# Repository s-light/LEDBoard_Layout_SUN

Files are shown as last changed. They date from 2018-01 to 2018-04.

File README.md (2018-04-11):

<!--lint disable list-item-indent-->

# LEDBoard Layout 'Sun'
'Sun' build with [LEDBoard 4x4 16bit](https://github.com/s-light/LEDBoard_4x4_16bit)

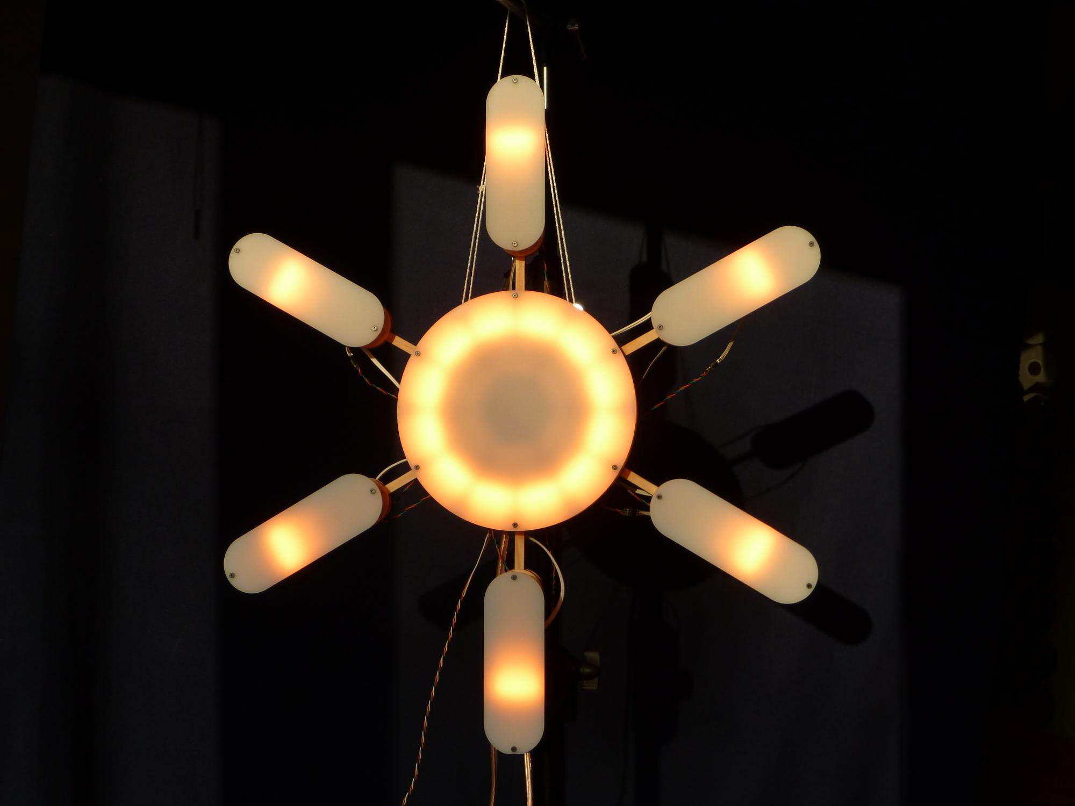
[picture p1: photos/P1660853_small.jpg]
Sun


[Video: LEDBoard Layout Sun - first test](https://vimeo.com/253356118)

## arduino test sketch
have a look at [sw/LEDBoard_HWTest_Sun](sw/LEDBoard_HWTest_Sun/readme.md)
how to setup an arduino board to do basic testings for the completed sun.

## control software
to control the sun / display content i have chosen to separate
this in two parts:

First i use an Arietta embedded linux board as
Network (Art-Net and E1.31 / sACN) two SPI/TLC5971 converter.
Additionally this should get basic 'playback' capabilities.
Something like  
`automatically start a rainbow loop on system-startup`  
--> for this task every embedded board should fit that has a free native SPI output
and can run debian based linux (for example Raspberry Pi) -
for ease of use i use the OLA software to create the Network-SPI bridge.
(currently there is a fork where i develop the [TLC5971 functionality](https://github.com/s-light/ola/tree/SPI_TLC5971_new))

Second there will be 'some Application' of some form running on an power-full
computer to generate the Data.
Ideas:
- [processing](https://processing.org/)
- [openFrameworks (OF)](http://openframeworks.cc/)
- [Pure Data (pd)](http://puredata.info/)

SW is a big TODO :-)

## mounting sun
in [mounting_sun/readme.md](mounting_sun/readme.md) are all information
regarding the Hardware / frame to build the sun.

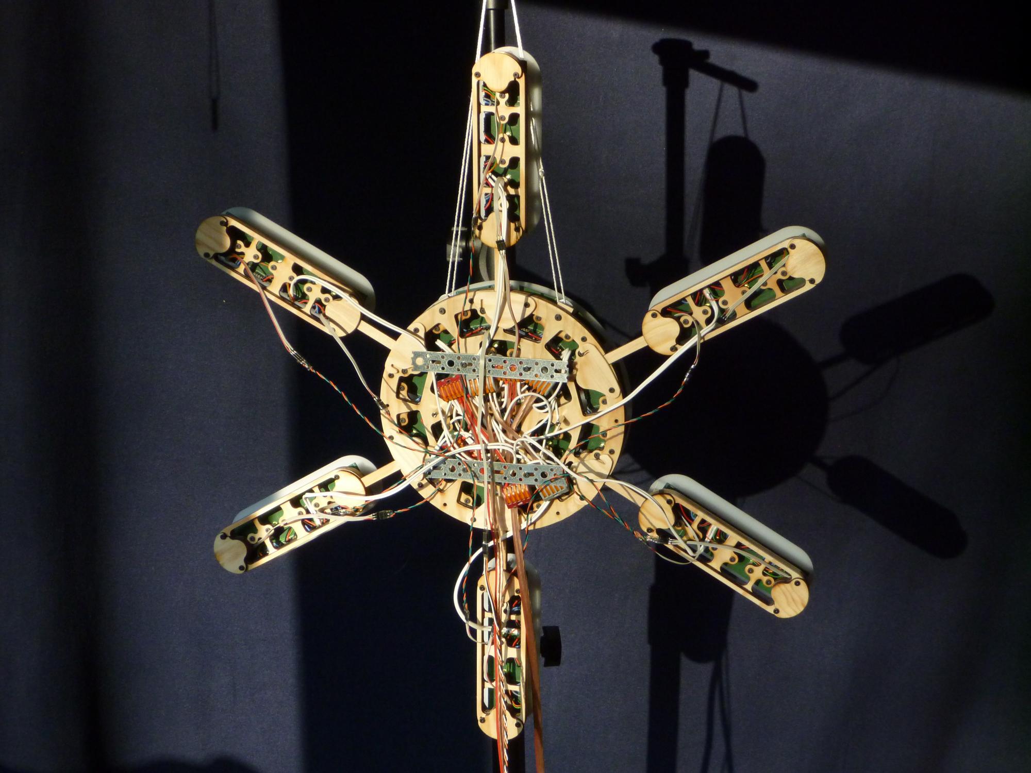
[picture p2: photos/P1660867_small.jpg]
Mounting Sun


---
# License
all* Software in this repository is license under MIT License (see [LICENSE file](LICENSE))

all* HW / Design files are licensed as CC-BY

\*besides if otherwise state at the files/subfolders themselves. 

<!-- License info -->
<a rel="license" href="http://creativecommons.org/licenses/by/4.0/">
    
</a><br />
<span xmlns:dct="http://purl.org/dc/terms/" property="dct:title">
    LEDBoard_Layout_Sun
</span>
by
<a xmlns:cc="http://creativecommons.org/ns#" href="https://github.com/s-light/LEDBoard_Layout_Sun" property="cc:attributionName" rel="cc:attributionURL">
    Stefan Krüger (s-light)
</a>
is licensed under a
<a rel="license" href="http://creativecommons.org/licenses/by/4.0/">
    Creative Commons Attribution 4.0 International License
</a>.

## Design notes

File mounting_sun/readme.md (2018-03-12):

<!--lint disable list-item-indent-->

# Mounting Sun

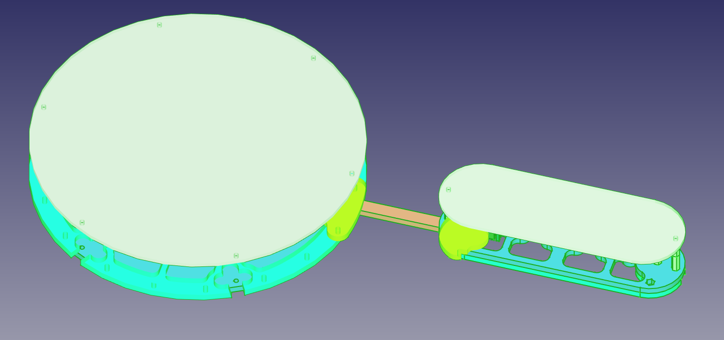
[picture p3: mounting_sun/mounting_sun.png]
Mounting Sun


full design: [mounting_sun.step](mounting_sun.step)

this is now version 2 - a redesign - this time made in FreeCAD v0.17 (daily) completely in 3d.

## parts-list

### laser-cutting
- Pine-Plywood (>=4mm thickness)
  - 6x [arm/arm_base.svg](arm/arm_base.svg)
  - 2x6x [arm/arm_socket.svg](arm/arm_socket.svg)
  - 12x [arm/arm_lock.svg](arm/arm_lock.svg)
  - 2x6x [connector/socket_connector_40mm.svg](connector/socket_connector_40mm.svg)
  - 6x [center/center_lock.svg](center/center_lock.svg)
  - 1x [center/center_base.svg](center/center_base.svg)
  - 1x [center/center_socket.svg](center/center_socket.svg)
  - 1x [center/center_socket2.svg](center/center_socket2.svg)
- [Plexiglas WH02 (3mm)](https://www.plexiglas-shop.com/DE/de/einseitig-satiniert-d3k0ydk22v3/plexiglas-satinice-weiss-wh02-sc-1jmuadz2jyj~p.html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)
  - 6x [arm/arm_diffusor.svg](arm/arm_diffusor.svg)
  - 1x [center/center_diffusor.svg](center/center_diffusor.svg)

### screws for LEDBoard mounting:
TODO: recalculate screws...
- 38*2*2 (=152)x [cylinder head - screw M3x10mm](https://www.wegertseder.com/ArticleDetails.aspx?ANR=2588-412)
- 38*2 (=76) [spacer M3x15mm](https://www.reichelt.de/index.html?ARTICLE=7120&GROUPID=7758&artnr=DI+15MM)

### screws for wood connections:
- 6*3 (=18)x [countersunk - screw M3x20mm](https://www.wegertseder.com/ArticleDetails.aspx?ANR=2606-242)
- 6*3 (=18)x [bolt M3](https://www.wegertseder.com/ArticleDetails.aspx?AKNUM=3991)

### cable

TODO:
for LEDBoard interconnections see Interconnection cables
cable type: 0,8mm solid copper conductor --> has to tightly fit in the LEDBoard sockets

#### power
- 2* 2m for main supply [4mm² Loudspeaker wire](https://www.reichelt.de/index.html?ARTICLE=9887&GROUPID=5034&artnr=LAT+400-5)
- 6* 350mm for arm supply [0.5mm² Loudspeaker wire](https://www.reichelt.de/index.html?ARTICLE=74777&GROUPID=5034&artnr=LAW+205-10)

### Power Supply
TODO

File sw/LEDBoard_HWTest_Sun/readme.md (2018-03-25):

<!--lint disable list-item-indent-->

# LEDBoard_HWTest_Sun

You need an Arduino compatible micro controller with a good amount of RAM.
i successfully tested an ATmega1284.
(32U4 is to small.)

This sketch has some Test-Patterns that use the full board-count of the sun.
One problem is the update rate.
as an simple  for loop to set all channels individually takes 36ms -
there is an additional 1ms to write data out to the tlc chips.

the sketch receives 5 channels of DMX from an external controller.
this setup is done so you can control this with with the
[LSM303_to_DMX](https://github.com/s-light/LSM303_to_DMX) Sketch.

the DMX receiving has some glitches and sometimes generates wrong values.
this only happens when the rendering/update process is active: `sequencer_running == true`
so seems there is some timing or interference problems in the thing...

the external control is active in only some of the sequence modes.
mainly in `sequencer_SPIRAL`:
- heading of the LSM303 controls the color (Hue),
- Y-Axis controls `sequencer_interval` mapped as 100-2000ms

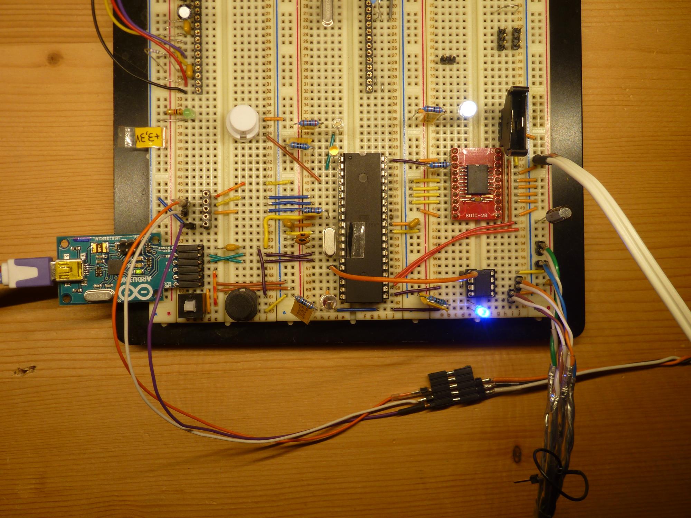
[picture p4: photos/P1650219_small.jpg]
test setup


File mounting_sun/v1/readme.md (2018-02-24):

<!--lint disable list-item-indent-->

# Mounting Sun

Mounting Sun

full design: [mounting_sun.step ](mounting_sun.svg)

this is now version 2 - a redesign - this time made in FreeCAD v0.17 (daily) completely in 3d.

## parts-list

### laser-cutting
- Wood (5mm thickness)
  - 6x [mounting_sun_arm_wood.svg](mounting_sun_arm_wood.svg)
  - 1x [mounting_sun_center_wood.svg](mounting_sun_center_wood.svg)
  - 6x [mounting_sun_connectors_wood.svg](mounting_sun_connectors_wood.svg)
- [Plexiglas WH02 (3mm)](https://www.plexiglas-shop.com/DE/de/einseitig-satiniert-d3k0ydk22v3/plexiglas-satinice-weiss-wh02-sc-1jmuadz2jyj~p.html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)
  - 6x [mounting_sun_arm_acryl.svg](mounting_sun_arm_acryl.svg)
  - 1x [mounting_sun_center_acryl.svg](mounting_sun_center_acryl.svg)

### screws for LEDBoard mounting:
- 38*2*2 (=152)x [cylinder head - screw M3x10mm](https://www.wegertseder.com/ArticleDetails.aspx?ANR=2588-412)
- 38*2 (=76) [spacer M3x15mm](https://www.reichelt.de/index.html?ARTICLE=7120&GROUPID=7758&artnr=DI+15MM)

### screws for wood connections:
- 6*3 (=18)x [countersunk - screw M3x20mm](https://www.wegertseder.com/ArticleDetails.aspx?ANR=2606-242)
- 6*3 (=18)x [bolt M3](https://www.wegertseder.com/ArticleDetails.aspx?AKNUM=3991)

### cable

TODO:
for LEDBoard interconnections see Interconnection cables
cable type: 0,8mm solid copper conductor --> has to tightly fit in the LEDBoard sockets

#### power
- 2* 2m for main supply [4mm² Loudspeaker wire](https://www.reichelt.de/index.html?ARTICLE=9887&GROUPID=5034&artnr=LAT+400-5)
- 6* 350mm for arm supply [0.5mm² Loudspeaker wire](https://www.reichelt.de/index.html?ARTICLE=74777&GROUPID=5034&artnr=LAW+205-10)

### Power Supply
TODO

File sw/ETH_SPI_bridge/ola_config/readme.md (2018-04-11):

<!--lint disable list-item-indent-->
# Mapping information:

the [ola_config](/ola_config) folder contains a set of olad configuration files.

these map the following Parts of the sun to universes:
## Center Part
- Starting on the top
- counting clockwise
- from outside to the inside

| Section | LEDBoards  | Universe |
| :--- | :--- | ---: |
| outer_ring_p1 | 1..4 | 1 |
| outer_ring_p2 | 5..8 | 2 |
| outer_ring_p3 | 9..12 | 3 |
| inner_ring_p1 | 13, 14, 15 | 4 |
| inner_ring_p2 | 16, 17, 18 | 5 |
| center_board  | 19 | 6 |

## Arms
- Starting on the top
- counting clockwise
- per arm - from inside to the outside

| Section | LEDBoards | Universe |
| :--- | :--- | ---: |
| arm_1 | 20..23 | 7 |
| arm_2 | 24..27 | 8 |
| arm_3 | 28..31 | 9 |
| arm_4 | 32..35 | 10 |
| arm_5 | 36..39 | 11 |
| arm_6 | 40..43 | 12 |

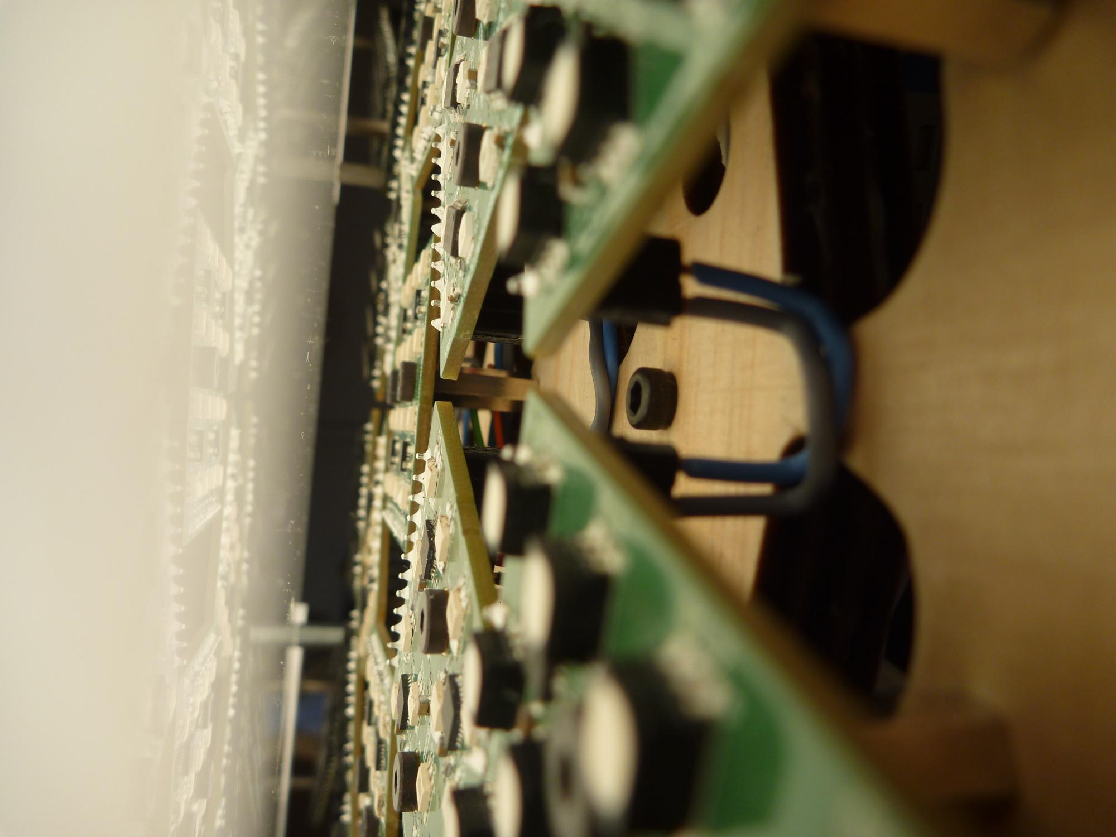
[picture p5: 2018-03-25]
photos/P1660885_small.jpg

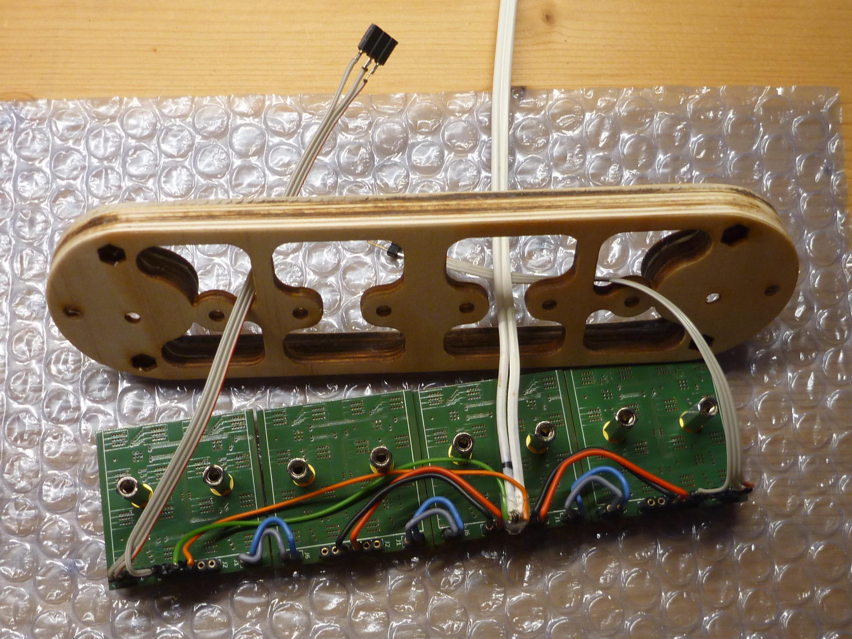
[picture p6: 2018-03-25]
photos/P1660823_crop.jpg

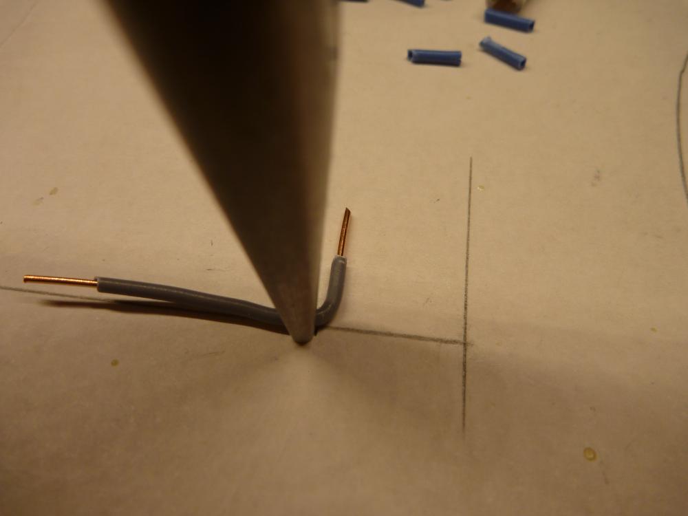
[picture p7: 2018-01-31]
photos/P1640711_small.jpg

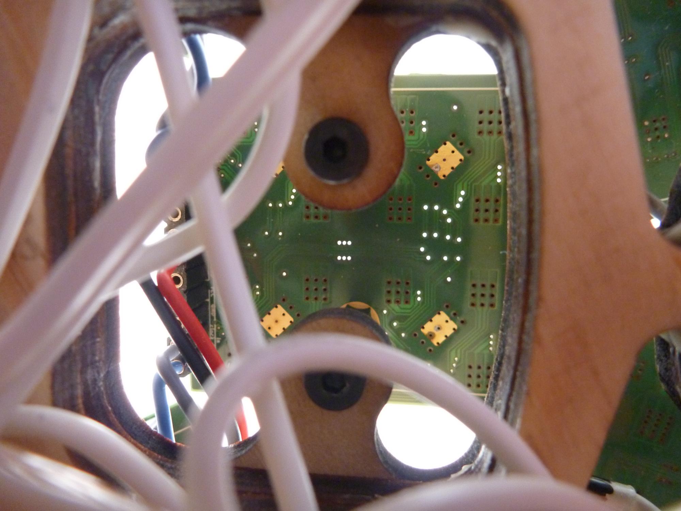
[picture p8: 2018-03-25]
photos/P1660899_small.jpg

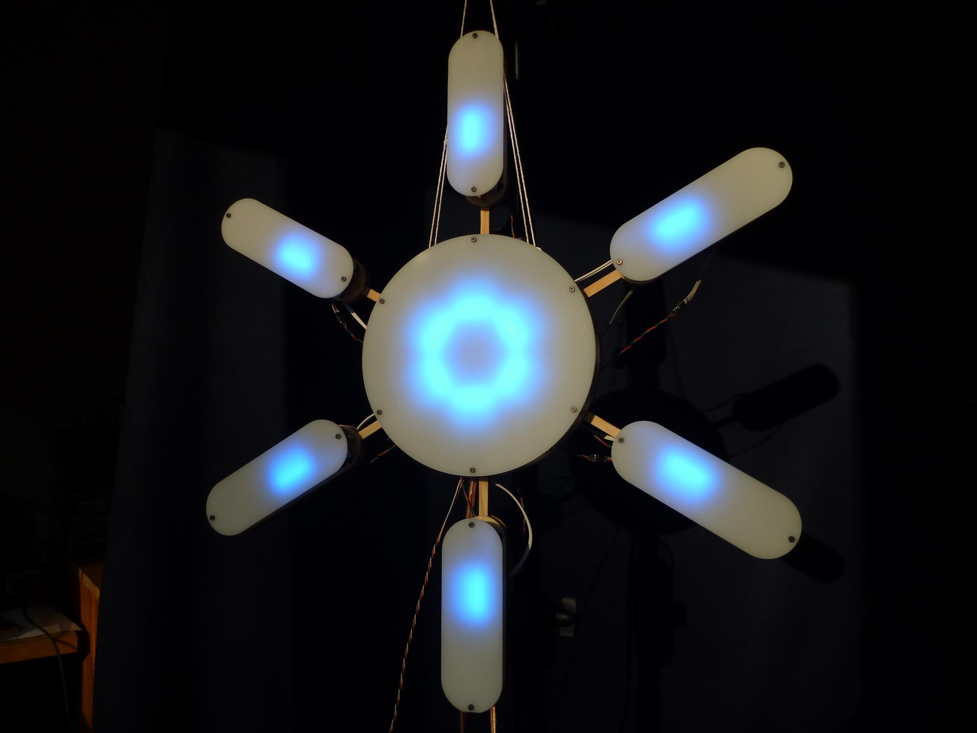
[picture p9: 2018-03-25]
photos/P1660846_small.jpg

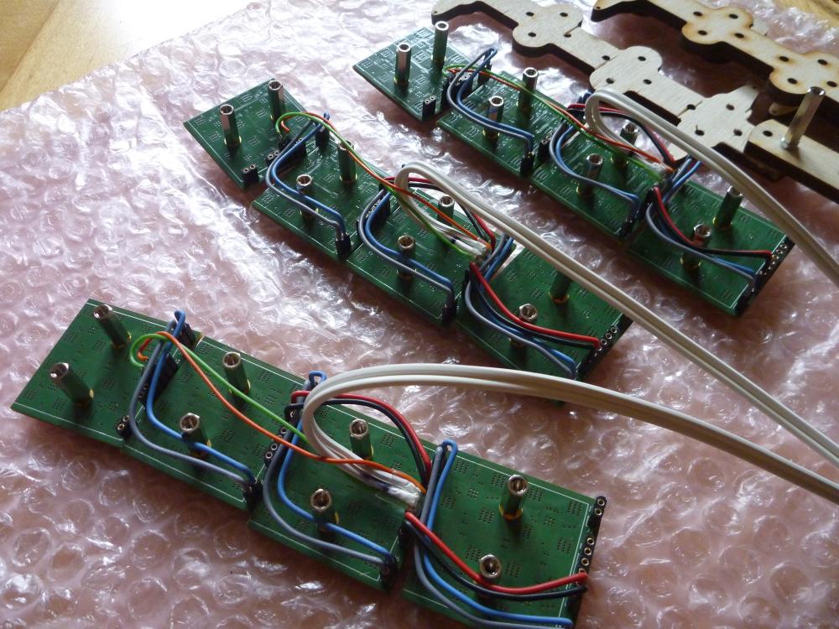
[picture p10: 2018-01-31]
photos/P1650089_small.jpg

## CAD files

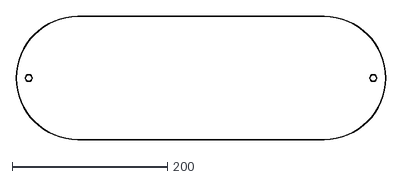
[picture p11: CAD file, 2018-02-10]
mounting_sun/arm/arm_diffusor.dxf
476.2 x 158.8

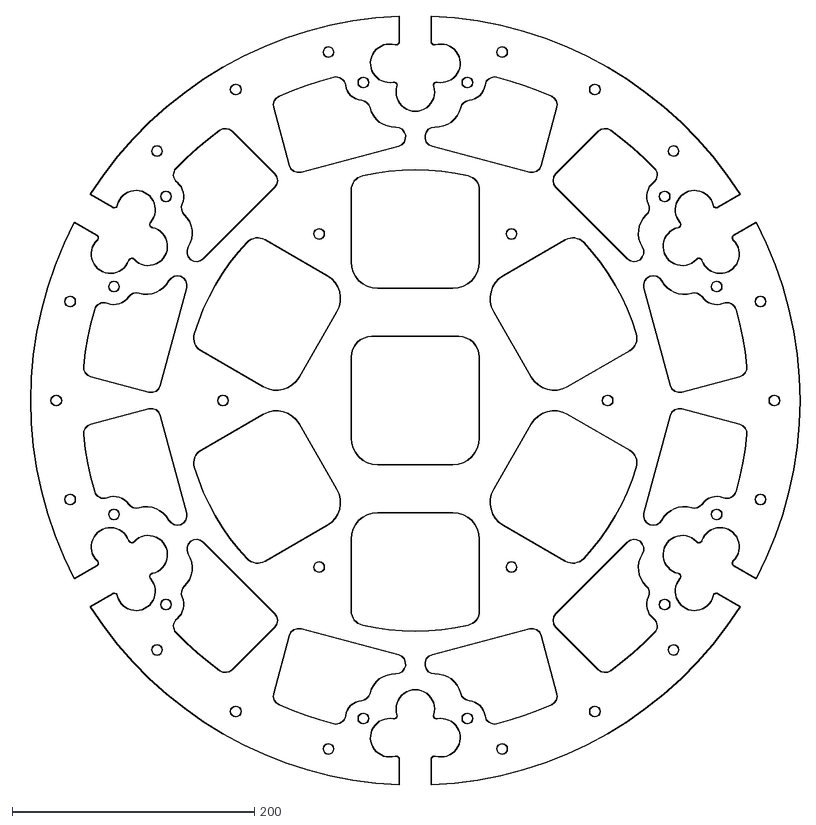
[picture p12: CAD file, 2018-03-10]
mounting_sun/center/center_socket2.dxf
647.1 x 634.4

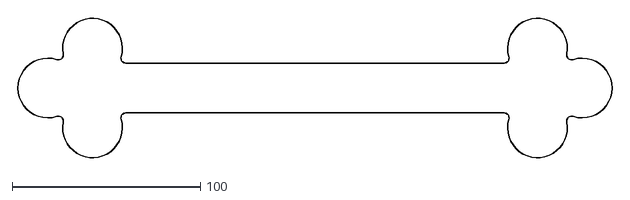
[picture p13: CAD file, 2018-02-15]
mounting_sun/connector/socket_connector_60mm.dxf
318.0 x 76.3

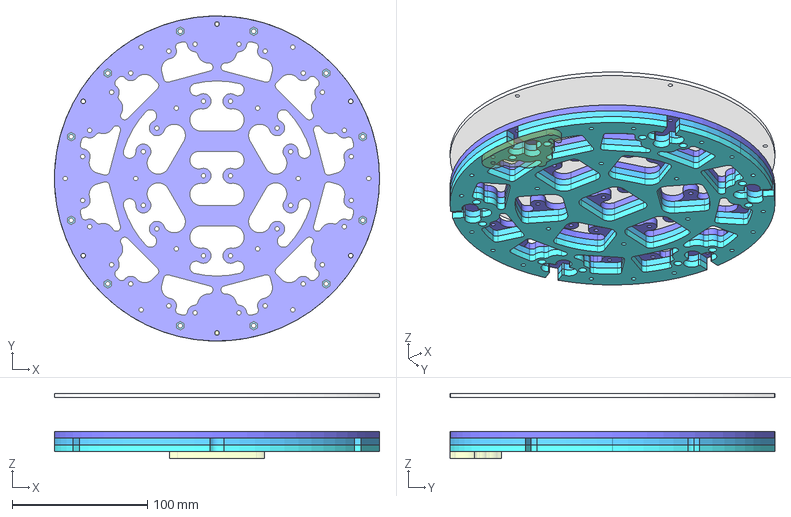
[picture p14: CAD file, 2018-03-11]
mounting_sun/mounting_sun.fcstd
240.0 x 239.9 x 48.0 mm
center_base_Body
center_socket_Body
center_diffusor_Body
center_lock_Body
center_socket2_Body

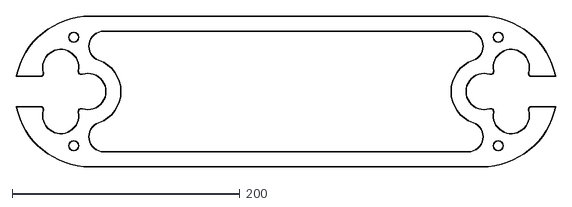
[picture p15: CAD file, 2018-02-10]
mounting_sun/arm/arm_socket.dxf
473.6 x 132.3

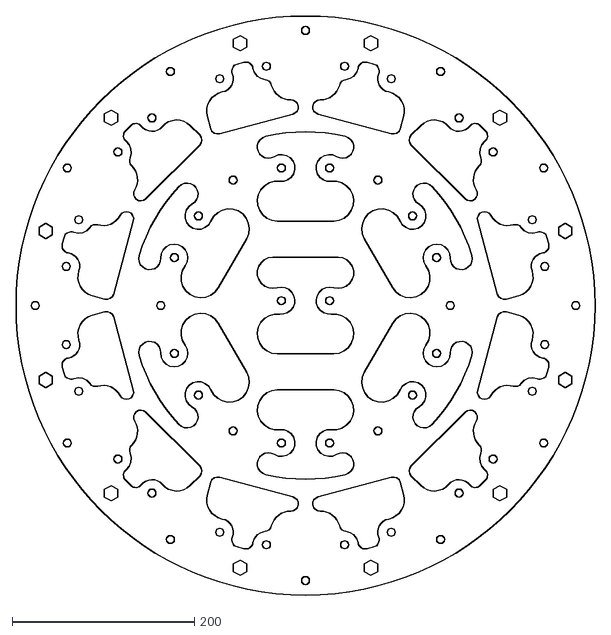
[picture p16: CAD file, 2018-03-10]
mounting_sun/center/center_base.dxf
635.0 x 635.0

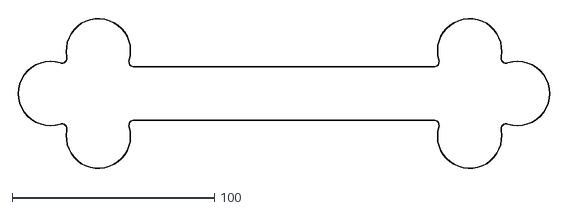
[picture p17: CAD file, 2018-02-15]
mounting_sun/connector/socket_connector_40mm.dxf
265.0 x 76.3

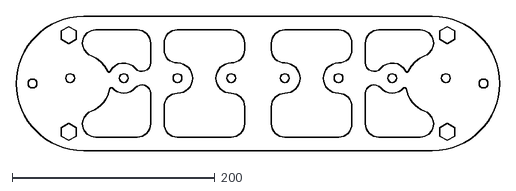
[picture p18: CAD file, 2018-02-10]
mounting_sun/arm/arm_base.dxf
476.2 x 132.3

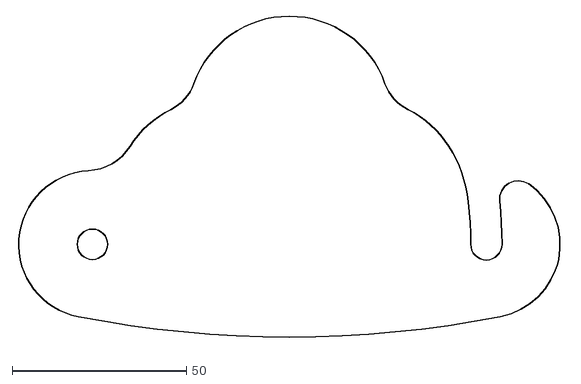
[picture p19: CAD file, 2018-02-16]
mounting_sun/center/center_lock.dxf
157.4 x 94.1

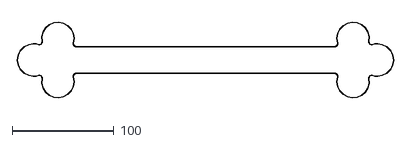
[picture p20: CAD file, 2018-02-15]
mounting_sun/connector/socket_connector_80mm.dxf
370.9 x 76.3

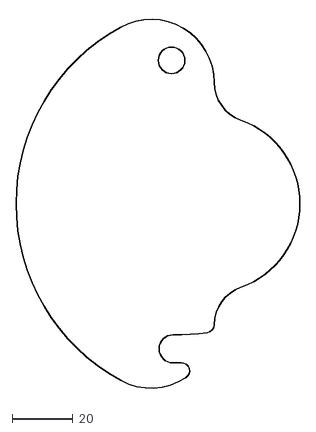
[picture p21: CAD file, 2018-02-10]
mounting_sun/arm/arm_lock.dxf
93.2 x 123.2

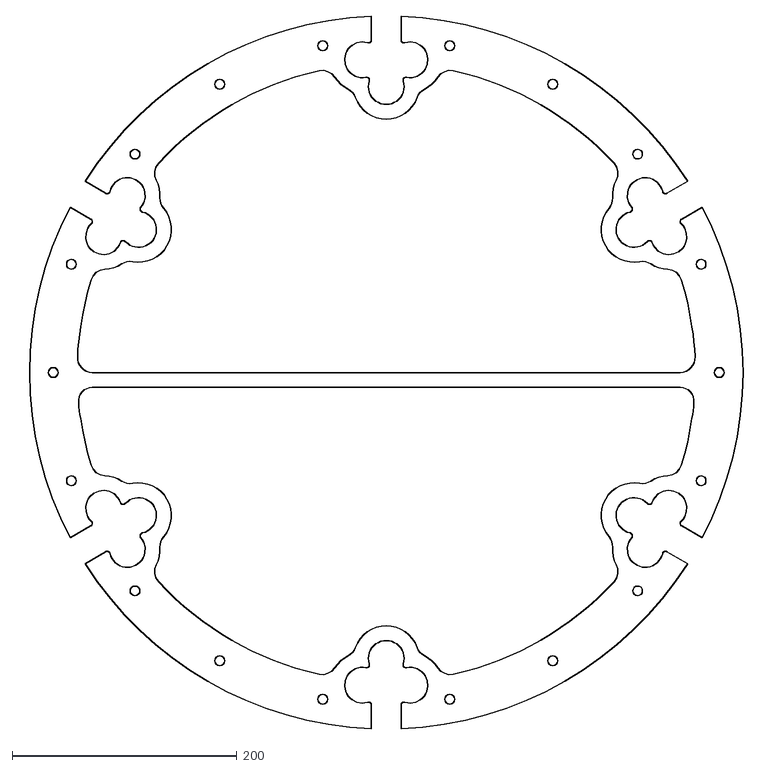
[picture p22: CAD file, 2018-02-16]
mounting_sun/center/center_socket.dxf
647.1 x 634.4

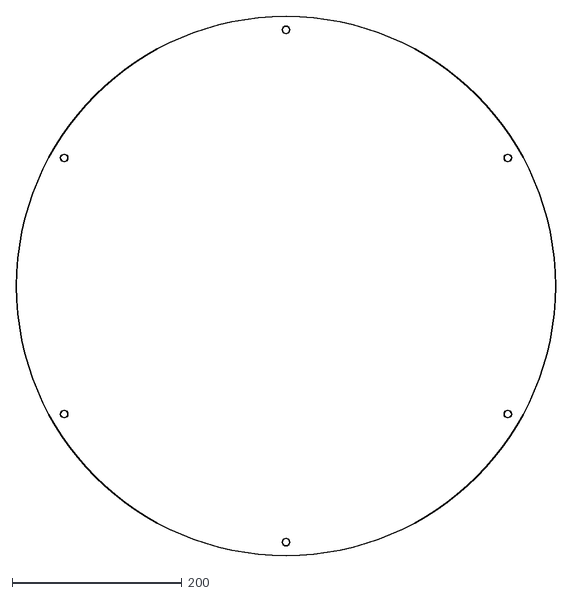
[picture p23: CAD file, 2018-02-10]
mounting_sun/center/center_diffusor.dxf
635.0 x 635.0

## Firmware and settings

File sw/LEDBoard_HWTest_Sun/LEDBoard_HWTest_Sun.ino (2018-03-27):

/******************************************************************************

    LEDBoard_HWTest_Sun
        test software for LEDBoard_4x4_16bit in mounting_sun
        debugout on usbserial interface: 115200baud

    hardware:
        Board:
            Arduino compatible (with serial port)
            with big RAM
            best fit: ATmega1284
            LED on pin 13
        Connections:
            D4 --> push button to GND
            SCK --> Clock input of TLC5791
            MOSI --> Data input of TLC5791
            only if TLC5791 is used with 5V@ VCC and VREG
            see www.ti.com/lit/ds/symlink/tlc5971.pdf
            page31 9.3 System Examples - Figure 38
            (eventually use a 74HC4050 as Levelshifter 5V-->3.8V
            if you use different VCC/VREG for Chips.)


    libraries used:
        ~ slight_DebugMenu
        ~ slight_Button
        ~ slight_FaderLin
            License: MIT
            written by stefan krueger (s-light),
                github@s-light.eu, http://s-light.eu, https://github.com/s-light/
        ~ Tlc59711.h
            License: MIT
            Copyright (c) 2016 Ulrich Stern
            https://github.com/ulrichstern/Tlc59711
        ~ DMXSerial
            Copyright (c) 2005-2012 by Matthias Hertel,
            http://www.mathertel.de
            license:
                See http://www.mathertel.de/License.aspx
                Software License Agreement (BSD License)

    written by stefan krueger (s-light),
        github@s-light.eu, http://s-light.eu, https://github.com/s-light/

    changelog / history
        check git commit messages

******************************************************************************/
/******************************************************************************
    The MIT License (MIT)

    Copyright (c) 2018 Stefan Krüger

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
    THE SOFTWARE IS PROVIDED "AS IS", WITHOUT WARRANTY OF ANY KIND, EXPRESS OR
    IMPLIED, INCLUDING BUT NOT LIMITED TO THE WARRANTIES OF MERCHANTABILITY,
    FITNESS FOR A PARTICULAR PURPOSE AND NONINFRINGEMENT. IN NO EVENT SHALL THE
    AUTHORS OR COPYRIGHT HOLDERS BE LIABLE FOR ANY CLAIM, DAMAGES OR OTHER
    LIABILITY, WHETHER IN AN ACTION OF CONTRACT, TORT OR OTHERWISE, ARISING FROM,
    OUT OF OR IN CONNECTION WITH THE SOFTWARE OR THE USE OR OTHER DEALINGS IN THE
    SOFTWARE.
******************************************************************************/

//~~~~~~~~~~~~~~~~~~~~~~~~~~~~~~~~~~~~~~~~~~~~~~~~~~~~~~~~~~~~~~~~~~~~
// Includes
//~~~~~~~~~~~~~~~~~~~~~~~~~~~~~~~~~~~~~~~~~~~~~~~~~~~~~~~~~~~~~~~~~~~~
// use "file.h" for files in same directory as .ino
// #include "file.h"
// use <file.h> for files in library directory
// #include <file.h>

#include <slight_DebugMenu.h>
#include <slight_FaderLin.h>
#include <slight_ButtonInput.h>

#include "LEDBoard.h"
#include "effect_engine.h"
#include "dmx_handling.h"

// create alias for namespace
namespace effe = effect_engine;

//~~~~~~~~~~~~~~~~~~~~~~~~~~~~~~~~~~~~~~~~~~~~~~~~~~~~~~~~~~~~~~~~~~~~
// Info
//~~~~~~~~~~~~~~~~~~~~~~~~~~~~~~~~~~~~~~~~~~~~~~~~~~~~~~~~~~~~~~~~~~~~
void sketchinfo_print(Print &out) {
    out.println();
    //             "|~~~~~~~~~|~~~~~~~~~|~~~..~~~|~~~~~~~~~|~~~~~~~~~|"
    out.println(F("~~~~~~~~~~~~~~~~~~~~~~~~~~~~~~~~~~~~~~~~~~~~~~~~~~"));
    out.println(F("|                       ^ ^                      |"));
    out.println(F("|                      (0,0)                     |"));
    out.println(F("|                      ( _ )                     |"));
    out.println(F("|                       \" \"                      |"));
    out.println(F("~~~~~~~~~~~~~~~~~~~~~~~~~~~~~~~~~~~~~~~~~~~~~~~~~~"));
    out.println(F("| LEDBoard_HWTest_Sun.ino"));
    out.println(F("|   Test LEDBoard_Layout_Sun"));
    out.println(F("|"));
    out.println(F("| This Sketch has a debug-menu:"));
    out.println(F("| send '?'+Return for help"));
    out.println(F("|"));
    out.println(F("| dream on & have fun :-)"));
    out.println(F("|"));
    out.println(F("~~~~~~~~~~~~~~~~~~~~~~~~~~~~~~~~~~~~~~~~~~~~~~~~~~"));
    out.println(F("|"));
    //out.println(F("| Version: Nov 11 2013  20:35:04"));
    out.print(F("| version: "));
    out.print(F(__DATE__));
    out.print(F("  "));
    out.print(F(__TIME__));
    out.println();
    out.println(F("|"));
    out.println(F("~~~~~~~~~~~~~~~~~~~~~~~~~~~~~~~~~~~~~~~~~~~~~~~~~~"));
    out.println();

    //out.println(__DATE__); Nov 11 2013
    //out.println(__TIME__); 20:35:04
}


// Serial.print to Flash: Notepad++ Replace RegEx
//     Find what:        Serial.print(.*)\("(.*)"\);
//     Replace with:    Serial.print\1\(F\("\2"\)\);



//~~~~~~~~~~~~~~~~~~~~~~~~~~~~~~~~~~~~~~~~~~~~~~~~~~~~~~~~~~~~~~~~~~~~
// definitions (global)
//~~~~~~~~~~~~~~~~~~~~~~~~~~~~~~~~~~~~~~~~~~~~~~~~~~~~~~~~~~~~~~~~~~~~


//~~~~~~~~~~~~~~~~~~~~~~~~~~~~~~~~~~~~~~~~~~
// Debug Output

Print &DebugOut = Serial;
Stream &DebugIn = Serial;
// attention: in setup_DebugOut 'Serial' is hardcoded used for initialisation


boolean infoled_state = 0;
const byte infoled_pin = 1;

unsigned long debugOut_LiveSign_TimeStamp_LastAction = 0;
const uint16_t debugOut_LiveSign_UpdateInterval = 1000; //ms

boolean debugOut_LiveSign_Serial_Enabled = 0;
boolean debugOut_LiveSign_LED_Enabled = 1;

unsigned long debugOut_dmx_TimeStamp_LastAction = 0;
const uint16_t debugOut_dmx_UpdateInterval = 500; //ms

boolean debugOut_dmx_Enabled = 0;

//~~~~~~~~~~~~~~~~~~~~~~~~~~~~~~~~~~~~~~~~~~
// Menu

// slight_DebugMenu(Stream &in_ref, Print &out_ref, uint8_t input_length_new);
slight_DebugMenu myDebugMenu(Serial, Serial, 15);

//~~~~~~~~~~~~~~~~~~~~~~~~~~~~~~~~~~~~~~~~~~
// button

const uint8_t button_pin = 3;

slight_ButtonInput button(
    0,  // byte cbID_New
    button_pin,  // byte cbPin_New,
    button_getInput,  // tCbfuncGetInput cbfuncGetInput_New,
    button_onEvent,  // tcbfOnEvent cbfCallbackOnEvent_New,
      30,  // const uint16_t cwDuration_Debounce_New = 30,
     500,  // const uint16_t cwDuration_HoldingDown_New = 1000,
      50,  // const uint16_t cwDuration_ClickSingle_New =   50,
     500,  // const uint16_t cwDuration_ClickLong_New =   3000,
     500   // const uint16_t cwDuration_ClickDouble_New = 1000
);

//~~~~~~~~~~~~~~~~~~~~~~~~~~~~~~~~~~~~~~~~~~
// FaderLin

const uint8_t myFaderRGB__channel_count = LEDBoard::colors_per_led;
slight_FaderLin myFaderRGB(
    0, // byte cbID_New
    myFaderRGB__channel_count, // byte cbChannelCount_New
    myFaderRGB_callback_OutputChanged, // tCbfuncValuesChanged cbfuncValuesChanged_New
    myCallback_onEvent // tCbfuncStateChanged cbfuncStateChanged_New
);


//~~~~~~~~~~~~~~~~~~~~~~~~~~~~~~~~~~~~~~~~~~
// lowbat

const uint8_t bat_voltage_pin = A0;
const uint8_t lowbat_warning_pin = 3;

uint16_t bat_voltage = 420;

uint32_t lowbat_timestamp_last = millis();
uint32_t lowbat_interval = 1000;


//~~~~~~~~~~~~~~~~~~~~~~~~~~~~~~~~~~~~~~~~~~
// other things..

//~~~~~~~~~~~~~~~~~~~~~~~~~~~~~~~~~~~~~~~~~~~~~~~~~~~~~~~~~~~~~~~~~~~~
// functions
//~~~~~~~~~~~~~~~~~~~~~~~~~~~~~~~~~~~~~~~~~~~~~~~~~~~~~~~~~~~~~~~~~~~~

//~~~~~~~~~~~~~~~~~~~~~~~~~~~~~~~~~~~~~~~~~~
// DebugOut

// freeRam found at
// http://forum.arduino.cc/index.php?topic=183790.msg1362282#msg1362282
// posted by mrburnette
int freeRam () {
    extern int __heap_start, *__brkval;
    int v;
    return (int) &v - (__brkval == 0 ? (int) &__heap_start : (int) __brkval);
}

void setup_DebugOut(Print &out) {
    // for ATmega32U4 devices:
    #if defined (__AVR_ATmega32U4__)
        // wait for arduino IDE to release all serial ports after upload.
        // delay(2000);
    #endif

    Serial.begin(115200);

    // for ATmega32U4 devices:
    #if defined (__AVR_ATmega32U4__)
        // Wait for Serial Connection to be Opend from Host or
        // timeout after 6second
        uint32_t timeStamp_Start = millis();
        while( (! Serial) && ( (millis() - timeStamp_Start) < 1000 ) ) {
            // nothing to do
        }
    #endif


    out.println();

    out.print(F("# Free RAM = "));
    out.println(freeRam());
}

void handle_debugout(Print &out) {
    if (
        (millis() - debugOut_LiveSign_TimeStamp_LastAction) >
        debugOut_LiveSign_UpdateInterval
    ) {
        debugOut_LiveSign_TimeStamp_LastAction = millis();

        if ( debugOut_LiveSign_Serial_Enabled ) {
            out.print(millis());
            out.print(F("ms;"));
            out.print(F("  free RAM = "));
            out.print(freeRam());
            // out.print(F("; bat votlage: "));
            // out.print(bat_voltage/100.0);
            // out.print(F("V"));
            out.println();
        }

        if ( debugOut_LiveSign_LED_Enabled ) {
            infoled_state = ! infoled_state;
            if (infoled_state) {
                //set LED to HIGH
                digitalWrite(infoled_pin, HIGH);
            } else {
                //set LED to LOW
                digitalWrite(infoled_pin, LOW);
            }
        }

    }
}

void handle_debugout_dmx(Print &out) {

    if ( debugOut_dmx_Enabled ) {
        if (
            (millis() - debugOut_dmx_TimeStamp_LastAction) >
            debugOut_dmx_UpdateInterval
        ) {
            debugOut_dmx_TimeStamp_LastAction = millis();
            dmx_handling::print_values(out);
            out.println();
            // dmx_handling::print_raw(out);
            // out.println();
        }
    }
}



//~~~~~~~~~~~~~~~~~~~~~~~~~~~~~~~~~~~~~~~~~~
// Menu System

void setup_DebugMenu(Print &out) {
    out.print(F("# Free RAM = "));
    out.println(freeRam());

    out.println(F("setup DebugMenu:")); {
        // myDebugMenu.set_user_EOC_char(';');
        myDebugMenu.set_callback(handleMenu_Main);
        myDebugMenu.begin();
    }
    out.println(F("\t finished."));
}

// Main Menu
void handleMenu_Main(slight_DebugMenu *pInstance) {
    Print &out = pInstance->get_stream_out_ref();
    char *command = pInstance->get_command_current_pointer();
    // out.print("command: '");
    // out.print(command);
    // out.println("'");
    switch (command[0]) {
        case 'h':
        case 'H':
        case '?': {
            // help
            out.println(F("____________________________________________________________"));
            out.println();
            out.println(F("Help for Commands:"));
            out.println();
            out.println(F("\t '?': this help"));
            out.println(F("\t 'i': sketch info"));
            out.println(F("\t 'y': toggle DebugOut livesign print"));
            out.println(F("\t 'Y': toggle DebugOut livesign LED"));
            out.println(F("\t 'x': tests"));
            out.println(F("\t 'X': test timings"));
            out.println();
            // out.println(F("\t 'A': Show 'HelloWorld' "));
            out.print(F("\t current sequencer: '"));
            out.print(effect_engine::sequencer_mode);
            out.println(F("'"));
            out.print(F("\t 'z': toggle sequencer_running ("));
            out.print(effect_engine::sequencer_running);
            out.println(F(")"));
            out.print(F("\t 'Z': toggle sequencer_direction ("));
            effect_engine::print_sequencer_direction(out);
            out.println(F(")"));
            out.println(F("\t 'o': sequencer off"));
            out.println(F("\t 'a': toggle CHANNELCHECK"));
            out.println(F("\t 'A': toggle SPIRAL"));
            out.println(F("\t 'b': toggle SPIRAL2"));
            out.println(F("\t 'B': toggle SUN SPIRAL"));
            out.println(F("\t 'c': toggle HORIZONTAL"));
            out.println(F("\t 'C': toggle SUN WAVE blue"));
            out.println(F("\t 'd': toggle SUN WAVE orange"));
            out.println();
            out.print(F("\t 'r': toggle effect_control ("));
            out.print(dmx_handling::effect_control);
            out.println(F(")"));
            out.print(F("\t 'R': toggle debugOut_dmx_Enabled ("));
            out.print(debugOut_dmx_Enabled);
            out.println(F(")"));
            out.print(F("\t 'e': toggle dmx serial out ("));
            out.print(dmx_handling::serial_out_enabled);
            out.println(F(")"));
            out.print(F("\t 'E': set dmx serial out interval 'i65535' ("));
            out.print(dmx_handling::serial_out_interval);
            out.println(F(")"));
            // ----------
            out.println();
            out.println(F("\t 's': sequencer single step 's'"));
            out.print(F("\t 'u': set sequencer interval 'u65535' ("));
            out.print(effe::sequencer_interval);
            out.println(F(")"));
            out.print(F("\t 'U': set calculate interval 'U65535' ("));
            out.print(effe::calculate_interval);
            out.println(F(")"));
            out.println();
            out.print(F("\t 'v': set effect value_low 'v65535' ("));
            out.print(effe::value_low);
            out.println(F(")"));
            out.print(F("\t 'V': set effect value_high 'V65535' ("));
            out.print(effe::value_high);
            out.println(F(")"));
            out.println();
            out.println();
            out.println(F("\t 'S': set channel 'S1:65535'"));
            // out.println(F("\t 'f': DemoFadeTo(ID, value) 'f1:65535'"));
            out.println();
            out.println(F("____________________________________________________________"));
        } break;
        case 'i': {
            sketchinfo_print(out);
        } break;
        case 'y': {
            out.println(F("\t toggle DebugOut livesign Serial:"));
            debugOut_LiveSign_Serial_Enabled = !debugOut_LiveSign_Serial_Enabled;
            out.print(F("\t debugOut_LiveSign_Serial_Enabled:"));
            out.println(debugOut_LiveSign_Serial_Enabled);
        } break;
        case 'Y': {
            out.println(F("\t toggle DebugOut livesign LED:"));
            debugOut_LiveSign_LED_Enabled = !debugOut_LiveSign_LED_Enabled;
            out.print(F("\t debugOut_LiveSign_LED_Enabled:"));
            out.println(debugOut_LiveSign_LED_Enabled);
        } break;
        case 'x': {
            out.println(F("__________"));
            out.println(F("Tests:"));

            out.println(F("nothing to do."));

            // uint16_t wTest = 65535;
            uint16_t wTest = atoi(&command[1]);
            out.print(F("wTest: "));
            out.print(wTest);
            out.println();

            out.print(F("1: "));
            out.print((byte)wTest);
            out.println();

            out.print(F("2: "));
            out.print((byte)(wTest>>8));
            out.println();

            out.println();

            out.println(F("__________"));
        } break;
        case 'X': {
            effect_engine::test_update(out);
        } break;
        //---------------------------------------------------------------------
        // case 'A': {
        //     out.println(F("\t Hello World! :-)"));
        // } break;
        case 'z': {
          out.print(F("\t toggle sequencer_running: "));
            effect_engine::sequencer_running = !effect_engine::sequencer_running;
            out.print(effect_engine::sequencer_running);
            out.print(F("\n"));
        } break;
        case 'Z': {
          out.print(F("\t toggle sequencer_direction: "));
            effect_engine::toggle_sequencer_direction(out);
        } break;
        case 'o': {
          out.print(F("\t sequencer_mode: OFF\n"));
            effe::toggle_sequencer(out, effe::sequencer_OFF, 1000);
        } break;
        case 'a': {
            out.println(F("\t toggle CHANNELCHECK:"));
            effe::toggle_sequencer(out, effe::sequencer_CHANNELCHECK, 1000);
        } break;
        case 'A': {
            out.println(F("\t toggle SPIRAL:"));
            effe::toggle_sequencer(out, effe::sequencer_SPIRAL, 1000);
        } break;
        case 'b': {
            out.println(F("\t toggle SPIRAL2:"));
            effe::toggle_sequencer(out, effe::sequencer_SPIRAL2, 100);
        } break;
        case 'B': {
            out.println(F("\t toggle SUN SPIRAL:"));
            effe::toggle_sequencer(out, effe::sequencer_SUN_SPIRAL, 100);
        } break;
        case 'c': {
            out.println(F("\t toggle HORIZONTAL:"));
            effe::toggle_sequencer(out, effe::sequencer_HORIZONTAL, 200);
        } break;
        case 'C': {
            out.println(F("\t toggle SUN_WAVE:"));
            effe::toggle_sequencer(out, effe::sequencer_SUN_WAVE_BLUE, 100);
        } break;
        case 'd': {
            out.println(F("\t toggle SUN_WAVE2:"));
            effe::toggle_sequencer(out, effe::sequencer_SUN_WAVE_ORANGE, 100);
        } break;
        // ------------------------------------------
        case 'r': {
            out.print(F("\t toggle effect_control:"));
            dmx_handling::effect_control = !dmx_handling::effect_control;
            out.print(dmx_handling::effect_control);
            out.println();
        } break;
        case 'R': {
            out.print(F("\t debugOut_dmx_Enabled:"));
            debugOut_dmx_Enabled = !debugOut_dmx_Enabled;
            out.print(debugOut_dmx_Enabled);
            out.println();
        } break;
        case 'e': {
            out.println(F("\t toggle dmx serial out"));
            dmx_handling::serial_out_enabled =
                !dmx_handling::serial_out_enabled;
        } break;
        case 'E': {
            out.print(F("\t set dmx serial out interval "));
            // convert part of string to int
            // (up to first char that is not a number)
            uint8_t command_offset = 1;
            uint16_t value = atoi(&command[command_offset]);
            out.print(value);
            out.println();
            dmx_handling::serial_out_interval = value;
        } break;
        // ------------------------------------------
        case 's': {
            out.println(F("\t sequencer single step  "));
            effect_engine::calculate_step();
            effect_engine::calculate_step_next();
        } break;
        case 'u': {
            out.print(F("\t set sequencer interval "));
            // convert part of string to int
            // (up to first char that is not a number)
            uint8_t command_offset = 1;
            uint16_t value = atoi(&command[command_offset]);
            out.print(value);
            out.println();
            effe::sequencer_interval = value;
        } break;
        case 'U': {
            out.print(F("\t set calculate interval "));
            uint8_t command_offset = 1;
            uint16_t value = atoi(&command[command_offset]);
            out.print(value);
            out.println();
            effe::calculate_interval = value;
        } break;
        case 'v': {
            out.print(F("\t set effect value_low"));
            // convert part of string to int
            // (up to first char that is not a number)
            uint8_t command_offset = 1;
            uint16_t value = atoi(&command[command_offset]);
            out.print(value);
            out.println();
            effe::value_low = value;
        } break;
        case 'V': {
            out.print(F("\t set effect value_high"));
            // convert part of string to int
            // (up to first char that is not a number)
            uint8_t command_offset = 1;
            uint16_t value = atoi(&command[command_offset]);
            out.print(value);
            out.println();
            effe::value_high = value;
        } break;
        // ------------------------------------------
        case 'S': {
            out.print(F("\t set channel "));
            // convert part of string to int
            // (up to first char that is not a number)
            uint8_t command_offset = 1;
            uint8_t ch = atoi(&command[command_offset]);
            // convert single character to int representation
            // uint8_t id = &command[1] - '0';
            command_offset = 3;
            if (ch > 9) {
                command_offset = command_offset +1;
            }
            out.print(ch);
            out.print(F(" : "));
            uint16_t value = atoi(&command[command_offset]);
            out.print(value);
            out.println();
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
void loop() {
    //~~~~~~~~~~~~~~~~~~~~~~~~~~~~~~~~~~~~~~~~~~
    // menu input
    myDebugMenu.update();

    //~~~~~~~~~~~~~~~~~~~~~~~~~~~~~~~~~~~~~~~~~~
    // update sub parts
    buttons_update();
    myFaderRGB.update();

    // lowbat_check();

    effect_engine::update();
    dmx_handling::update(DebugOut);

    handle_debugout(DebugOut);
    handle_debugout_dmx(DebugOut);
}

//~~~~~~~~~~~~~~~~~~~~~~~~~~~~~~~~~~~~~~~~~~~~~~~~~~~~~~~~~~~~~~~~~~~~
// THE END
//~~~~~~~~~~~~~~~~~~~~~~~~~~~~~~~~~~~~~~~~~~~~~~~~~~~~~~~~~~~~~~~~~~~~

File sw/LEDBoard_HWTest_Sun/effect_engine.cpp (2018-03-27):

/******************************************************************************

    effect engine

******************************************************************************/
/******************************************************************************
    The MIT License (MIT)

    Copyright (c) 2018 Stefan Krüger

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
    THE SOFTWARE IS PROVIDED "AS IS", WITHOUT WARRANTY OF ANY KIND, EXPRESS OR
    IMPLIED, INCLUDING BUT NOT LIMITED TO THE WARRANTIES OF MERCHANTABILITY,
    FITNESS FOR A PARTICULAR PURPOSE AND NONINFRINGEMENT. IN NO EVENT SHALL THE
    AUTHORS OR COPYRIGHT HOLDERS BE LIABLE FOR ANY CLAIM, DAMAGES OR OTHER
    LIABILITY, WHETHER IN AN ACTION OF CONTRACT, TORT OR OTHERWISE, ARISING FROM,
    OUT OF OR IN CONNECTION WITH THE SOFTWARE OR THE USE OR OTHER DEALINGS IN THE
    SOFTWARE.
******************************************************************************/

#include "./effect_engine.h"

namespace effect_engine {
//~~~~~~~~~~~~~~~~~~~~~~~~~~~~~~~~~~~~~~~~~~
// definitions
//~~~~~~~~~~~~~~~~~~~~~~~~~~~~~~~~~~~~~~~~~~

sequencer_modes sequencer_mode = sequencer_SUN_WAVE_ORANGE;

bool sequencer_running = true;

uint16_t value_low = 1;
uint16_t value_high = 1000;

uint32_t sequencer_timestamp_last = millis();
uint32_t sequencer_interval = 100;
uint32_t calculate_timestamp_last = millis();
uint32_t calculate_interval = 100;

int16_t sequencer_current_step = 0;
uint8_t sequencer_direction_forward = true;

uint16_t sequencer_color[LEDBoard::colors_per_led] = {     0, 10000,     0};

//~~~~~~~~~~~~~~~~~~~~~~~~~~~~~~~~~~~~~~~~~~
// private function definitions
//~~~~~~~~~~~~~~~~~~~~~~~~~~~~~~~~~~~~~~~~~~

// if they are in the correct order you don't need to define theme :-)

//~~~~~~~~~~~~~~~~~~~~~~~~~~~~~~~~~~~~~~~~~~
// private functions
//~~~~~~~~~~~~~~~~~~~~~~~~~~~~~~~~~~~~~~~~~~



// parse the pointer to the first element of the effect_map
void calculate_step__effectmap(
    const uint8_t *effect_map,
    const uint8_t row_count,
    const uint8_t column_count,
    const uint8_t board_start_index,
    // const uint16_t tail[][LEDBoard::colors_per_led],
    const uint16_t tail[][3],
    const uint8_t tail_count,
    const bool change_tail_direction = false,
    const uint8_t step_offset = 0
) {
    // Serial.println("calculate_step__effectmap: ");

    uint16_t ch_offset = LEDBoard::colorchannels_per_board * board_start_index;

    uint8_t boards_per_row = column_count / LEDBoard::leds_per_row;
    uint8_t boards_per_column = row_count / LEDBoard::leds_per_column;

    for (size_t row = 0; row < row_count; row++) {
        for (size_t column = 0; column < column_count; column++) {
            // Serial.print("step ");
            // print_aligned_int8(Serial, sequencer_current_step);
            // Serial.print("; r");
            // print_aligned_int8(Serial, row);
            // Serial.print("; c");
            // print_aligned_int8(Serial, column);

            uint8_t pixel = 0;
            uint16_t ch = 0;

            uint8_t board_column = column;
            uint8_t board_row = row;

            if (column >= LEDBoard::leds_per_row) {
                board_column = column % LEDBoard::leds_per_row;
            }
            if (row >= LEDBoard::leds_per_column) {
                board_row = row % LEDBoard::leds_per_column;
            }

            // Serial.print("; br: ");
            // print_aligned_int8(Serial, board_row);
            // Serial.print("; bc: ");
            // print_aligned_int8(Serial, board_column);

            // calculate board offset count

            uint8_t boards_offset_row = (row / LEDBoard::leds_per_column);
            uint8_t boards_offset_column = (column / LEDBoard::leds_per_row);
            uint8_t boards_offset =
                (boards_offset_row * boards_per_row) + boards_offset_column;
            // Serial.print("; bor: ");
            // print_aligned_int8(Serial, boards_offset_row);
            // Serial.print("; boc: ");
            // print_aligned_int8(Serial, boards_offset_column);
            // Serial.print("; bo: ");
            // print_aligned_int8(Serial, boards_offset);

            pixel = LEDBoard::channel_position_map[board_row][board_column];
            ch = pixel * 3;
            // Serial.print("; ch: ");
            // print_aligned_int16(Serial, ch);

            ch = ch +
                (LEDBoard::colorchannels_per_board * (uint16_t)boards_offset);
            // Serial.print("; ch: ");
            // print_aligned_int16(Serial, ch);

            // Serial.print("; ch_offset: ");
            // print_aligned_int16(Serial, ch_offset);

            // Serial.print("; pixel: ");
            // print_aligned_int8(Serial, pixel);
            // Serial.print("; ch: ");
            // print_aligned_int16(Serial, ch);


            // uint8_t effect_step = effect_map[row][column];
            int8_t effect_step = effect_map[(row *column_count) + column];
            // Serial.print("; effect_step: ");
            // print_aligned_int8(Serial, effect_step);
            effect_step += step_offset;
            // Serial.print("; effect_step: ");
            // print_aligned_int8(Serial, effect_step);

            // if (effect_step == sequencer_current_step) {
            //     // Serial.print(" ON");
            //     // set pixel to high
            //     values[ch + 0] = 20000;
            //     values[ch + 1] = 55000;
            //     values[ch + 2] = 0;
            //     // values[ch + 0] = 1000;
            //     // values[ch + 1] = 4000;
            //     // values[ch + 2] = 0;
            // }
            // else {
            //     // set pixel to low
            //     values[ch + 0] = 0;
            //     values[ch + 1] = 0;
            //     values[ch + 2] = 0;
            // }

            // tail
            int8_t tail_step = effect_step - sequencer_current_step;
            // Serial.print("; tail_step: ");
            // effect_engine::print_aligned_int8(Serial, tail_step);

            if (change_tail_direction && sequencer_direction_forward) {
                // change tail direction
                tail_step = (tail_count-1) - tail_step;
                // Serial.print("; tail_step: ");
                // effect_engine::print_aligned_int8(Serial, tail_step);
            }

            // add offset
            ch = ch_offset + ch;
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

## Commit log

2018-01-29 prepared Arduino TestSW
2018-01-30 fixed missing offset calculation in effect mapping; rearanged code..
    [LEDBoard_HWTest_Sun.ino]
2018-01-30 fixed serial menu sequencer toggle
    [LEDBoard_HWTest_Sun.ino]
2018-01-31 reworked wave effect to be able to use different colors
    [LEDBoard_HWTest_Sun.ino]
2018-02-06 fixed dmx value decoding
    [LEDBoard_HWTest_Sun.ino, dmx_handling.cpp, dmx_handling.h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]
2018-02-07 added effect_control to button sequencer switching
2018-02-09 constrain sequencer_interval to avoid 0 value glitches
    [dmx_handling.cpp]
2018-02-09 added step of LEDBoard_4x4_16bit module
2018-02-09 added new 3d construction
    [mounting_sun.fcstd]
2018-02-09 more design of v2
    [mounting_sun.fcstd]
2018-02-10 more updates..
    [mounting_sun.fcstd]
2018-02-10 arm about finished..
    [mounting_sun.fcstd]
2018-02-10 moved `mounting_sun.md` readme to subfolder
2018-02-10 design finished
    [mounting_sun.fcstd]
2018-02-10 added new design and export
    [mounting_sun.fcstd]
2018-02-10 added diffusor
    [arm_base.dxf, arm_diffusor.dxf, arm_lock.dxf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]
2018-02-11 started center_base
    [mounting_sun.fcstd]
2018-02-14 started center_base_cooling
    [mounting_sun.fcstd]
2018-02-14 center_base_cooling done :-)
    [mounting_sun.fcstd]
2018-02-14 started center_socket
    [mounting_sun.fcstd]
2018-02-14 center_socket finished
    [mounting_sun.fcstd]
2018-02-14 started center_lock
    [mounting_sun.fcstd]
2018-02-15 center finished
    [mounting_sun.fcstd]
2018-02-15 exported and cleaned up center_socket
    [center_socket.dxf]
2018-02-15 socket_connector done :-)
    [mounting_sun.fcstd]
2018-02-15 added connector 40mm, 60mm, 80mm
    [mounting_sun.fcstd]
2018-02-15 rearanged directory structure
    [arm_base.dxf, arm_diffusor.dxf, arm_lock.dxf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]
2018-02-15 exported socket_connector_*0mm & cleanup
    [mounting_sun.fcstd, socket_connector_40mm.dxf, socket_connector_60mm.dxf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]
2018-02-16 added center_*_ext_mounting holes
    [mounting_sun.fcstd]
2018-02-16 exported and cleaned center_*
    [center_base.dxf, center_lock.dxf, center_socket.dxf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]
2018-02-16 added image and step from construction model
    [mounting_sun.fcstd]
2018-02-23 redesigned center
    [mounting_sun.fcstd]
2018-02-23 added center LEDBoard
    [mounting_sun.fcstd]
2018-02-23 center redesign finished
    [mounting_sun.fcstd]
2018-02-24 updated readme with new laser-cutting parts list
2018-03-10 redesign cooling center
    [mounting_sun.fcstd]
2018-03-10 redesigned center lock (not finished)
    [mounting_sun.fcstd]
2018-03-10 done hopefully :-)
    [center_base.dxf, center_socket2.dxf, mounting_sun.fcstd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]
2018-03-11 fixed FreeCAD file for center
    [mounting_sun.fcstd, mounting_sun2.fcstd]
2018-03-11 updated lasercutting list
2018-03-19 prepare spi test
2018-03-19 added center_lock for printing - but its old layout!
2018-03-19 readded spi output mapping...
2018-03-19 set spi port count to 18
2018-03-24 code redesign for new layout done..
    [LEDBoard.h, effect_engine.cpp]
2018-03-27 changed default mode & button effect order
